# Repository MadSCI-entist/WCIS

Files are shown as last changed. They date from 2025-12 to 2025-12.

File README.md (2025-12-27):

WCIS – DIY Irrigation System Using ESP32

WCIS (Wirelessly Controlled Irrigation System) is an ESP32-based smart irrigation controller designed to control a solenoid valve for turning water flow ON and OFF automatically or manually.

WCIS uses an ESP32 microcontroller to control a DC solenoid valve through a MOSFET driver circuit.

The system can be expanded to include:

Scheduled irrigation (using NTP time)
Web-based control dashboard
Manual override

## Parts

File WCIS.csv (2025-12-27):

Value | Qty | Use
PCB | 1 | Electronics
10uF/10V(20%) | 1 | Electronics
0.1uF/50V(10%) | 3 | Electronics
22uF/10V(20%) | 1 | Electronics
22uF | 2 | Electronics
0.1uF | 2 | Electronics
IN4007 | 1 | Electronics
LESD5D5.0CT1G | 3 | Electronics
LED | 1 | Electronics
1N5819 | 2 | Electronics
USB_C_Receptacle_USB2.0_14P | 1 | Electronics
Screw_Terminal_01x02 | 1 | Electronics
SS8050 | 2 | Electronics
IRLML2502TRPBF | 1 | Electronics
22.1K(1%) | 1 | Electronics
47.5k(1%) | 1 | Electronics
2K(5%) | 1 | Electronics
0R | 2 | Electronics
10K(5%) | 3 | Electronics
10K(5%)NC | 1 | Electronics
2K | 1 | Electronics
1K THT | 1 | Electronics
SW_Push | 2 | Electronics
ESP32-WROOM-32 | 1 | Electronics
CP2102N-Axx-xQFN28 | 2 | Electronics
AMS1117-3.3 | 1 | Electronics
5V 3A Power Supply Type- C | 1 | Electronics
Solenoid Valve 5V | 1 | Electronics/Plumbing
10M 1/4" hose and Misting set | 1 | Plumbing
3M 1/3" Hose and Adapter | 1 | Plumbing

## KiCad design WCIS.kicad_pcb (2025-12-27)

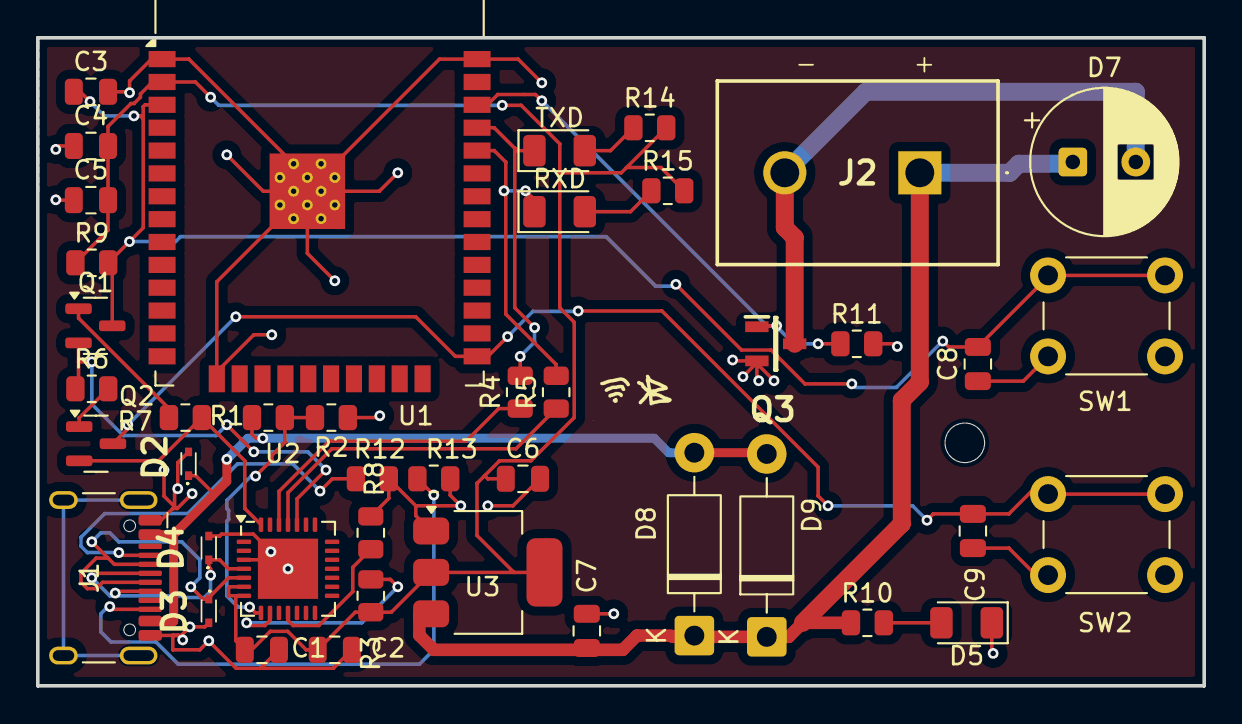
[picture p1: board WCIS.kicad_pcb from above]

Board: 2 copper layers, 64.8 x 36.0 mm, 43 parts (0 on the bottom side), 26 nets.

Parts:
C1: 10uF/10V(20%); C_0805_2012Metric
C2, C3, C5: 0.1uF/50V(10%); C_0805_2012Metric
C4: 22uF/10V(20%); C_0805_2012Metric
C6, C7: 22uF; C_0805_2012Metric
C8, C9: 0.1uF; C_0805_2012Metric
D2, D3, D4: LESD5D5.0CT1G; LESD5D50CT1G
D5: LED; LED_1206_3216Metric
D7: 1000uF; CP_Radial_D8.0mm_P3.50mm
D8, D9: 1N5819; D_DO-41_SOD81_P10.16mm_Horizontal
J1: USB_C_Receptacle_USB2.0_14P; USB_C_Receptacle_HCTL_HC-TYPE-C-16P-01A
J2: Screw_Terminal_01x02; TB00475002GR
Q1, Q2: SS8050; SOT-23
Q3: IRLML2502TRPBF; SOT95P237X112-3N
R1: 22.1K(1%); R_0805_2012Metric
R2: 47.5k(1%); R_0805_2012Metric
R3: 2K(5%); R_0805_2012Metric
R4, R5: 0R; R_0805_2012Metric
R6, R7, R9: 10K(5%); R_0805_2012Metric
R8: 10K(5%)NC; R_0805_2012Metric
R10: 2K; R_0805_2012Metric
R11: 33K; R_0805_2012Metric
R12: 5.1k; R_0805_2012Metric
R13: 5.1K; R_0805_2012Metric
R14, R15: 2.2K; R_0805_2012Metric
RXD: LED; LED_1206_3216Metric
SW1, SW2: SW_Push; SW_PUSH_6mm_H4.3mm
TXD: LED; LED_1206_3216Metric
U1: ESP32-WROOM-32
U2: CP2102N-Axx-xQFN28; QFN-28-1EP_5x5mm_P0.5mm_EP3.35x3.35mm
U3: AMS1117-3.3; SOT-223-3_TabPin2

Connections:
/DTR: Q2.2 (E), R7.1, U2.28 (~DTR)
/EN: C3.1, C8.2, Q1.3 (C), R9.2, SW1.2, U1.3 (EN)
/IO0: C9.2, Q2.3 (C), SW2.2, U1.25 (IO0)
/RTS: Q1.2 (E), R6.1, U2.24 (~RTS)
/RXD: R5.1, U2.25 (RXD)
/RXD0: R5.2, RXD.1 (K), U1.34 (RXD0/IO3)
/TXD: R4.1, U2.26 (TXD)
/TXD0: R4.2, TXD.1 (K), U1.35 (TXD0/IO1)
/USB+: D4.1, J1.A6 (D+), J1.B6 (D+), U2.4 (D+)
/USB-: D3.1, J1.A7 (D-), J1.B7 (D-), U2.5 (D-)
GND: C1.1, C2.1, C3.2, C4.1, C5.1, C6.2, C7.2, C8.1, C9.1, D2.2, D3.2, D4.2, D5.1 (K), J1.A1 (GND), J1.A12 (GND), J1.B1 (GND), J1.B12 (GND), Q3.2 (S), R2.1, R8.2, R11.2, R12.2, R13.2, SW1.1, SW2.1, U1.1 (GND), U1.15 (GND), U1.38 (GND), U1.39 (GND), U2.3 (GND), U2.29 (GND), U3.1 (GND)
IN_5V: C7.1, D7.1, D8.1 (K), D9.1 (K), J2.1, R10.1, U3.3 (VI)
unnamed: R14.1, TXD.2 (A)
unnamed: D5.2 (A), R10.2
unnamed: R15.1, RXD.2 (A)
unnamed: J1.A5 (CC1), R12.1
unnamed: J1.B5 (CC2), R13.1
unnamed: D7.2, J2.2, Q3.3 (D)
unnamed: Q1.1 (B), R7.2
unnamed: Q2.1 (B), R6.2
unnamed: Q3.1 (G), R11.1, U1.36 (IO22)
unnamed: R1.2, R2.2, U2.8 (VBUS)
unnamed: R3.2, U2.9 (~RST)
unnamed: R8.1, U2.11 (~SUSPEND)
VBUS: D2.1, D8.2 (A), D9.2 (A), J1.A4 (VBUS), J1.A9 (VBUS), J1.B4 (VBUS), J1.B9 (VBUS), R1.1
VDD33: C1.2, C2.2, C4.2, C5.2, C6.1, R3.1, R9.1, R14.2, R15.2, U1.2 (VDD), U2.6 (VDD), U2.7 (VREGIN), U3.2 (VO)

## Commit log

2025-12-27 KICAD files
    [WCIS.kicad_pcb, WCIS.kicad_sch]
2025-12-27 Bill Of Materials
    [WCIS.csv]
2025-12-27 Update WCIS.csv to add missing entries
    [WCIS.csv]
